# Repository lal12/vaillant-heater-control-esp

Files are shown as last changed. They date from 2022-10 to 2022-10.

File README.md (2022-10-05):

# Vaillant heater control

This project contains a little board (and software) to control a Vaillant heater.

It is currently Work in Progress and not everything works!!

## PCB

/kicad

The schematic shows a PCB which controls the Vaillant heater via 789 interface which is just an analog voltage to control the flow temperature (Vorlauftemperatur).

## Esphome

/esphome

A simple config to use the PCB with an ESP32.

## NodeJS

/nodejs

Small NodeJS application, it reads out the data from the heater.
It isn't really well made and more intended for temporary and debugging purposes.

It will log the data to the console and a json log.
It will display a graph on a little webpage.
It will publish the data to mqtt in a HomeAssistant compatible format.

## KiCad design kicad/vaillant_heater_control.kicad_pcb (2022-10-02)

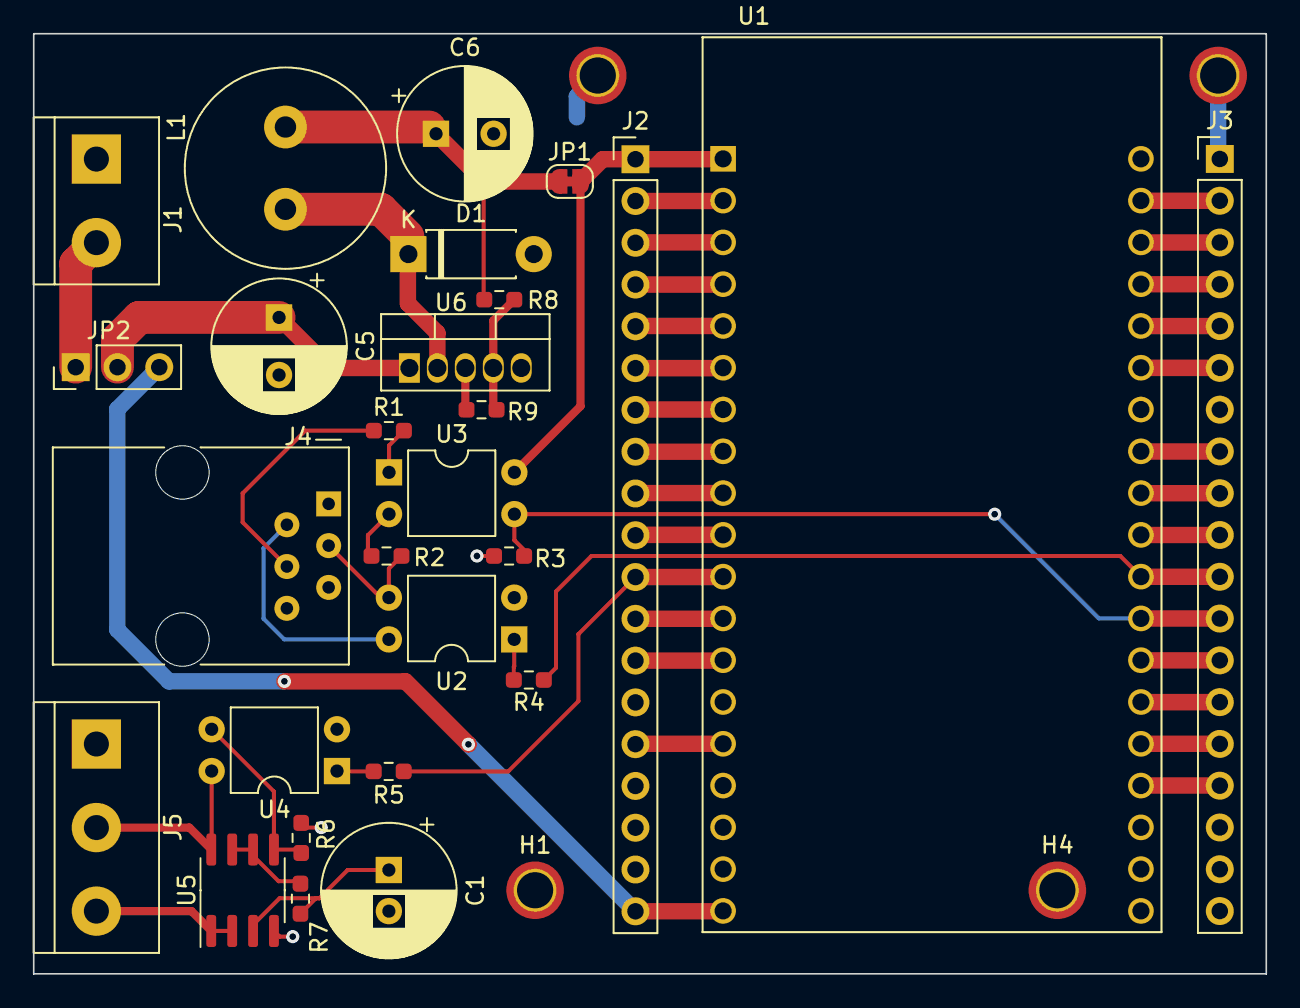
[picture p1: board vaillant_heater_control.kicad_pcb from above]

Board: 2 copper layers, 74.9 x 57.2 mm, 31 parts (0 on the bottom side), 48 nets.

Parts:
C1: 10u; CP_Radial_D8.0mm_P2.50mm
C5: 100u; CP_Radial_D8.0mm_P3.50mm
C6: 330u; CP_Radial_D8.0mm_P3.50mm
D1: 1n5819; D_DO-41_SOD81_P7.62mm_Horizontal
H1, H2, H3, H4: MountingHole_Pad; MountingHole_2.2mm_M2_ISO7380_Pad_TopBottom
J1: Screw_Terminal_01x02; TerminalBlock_bornier-2_P5.08mm
J2, J3: Conn_01x19; PinHeader_1x19_P2.54mm_Vertical
J4: 6P6C; RJ12_Amphenol_54601
J5: Screw_Terminal_01x03; TerminalBlock_bornier-3_P5.08mm
JP1: SolderJumper_2_Bridged; SolderJumper-2_P1.3mm_Bridged_RoundedPad1.0x1.5mm
JP2: Jumper_3_Bridged12; PinHeader_1x03_P2.54mm_Vertical
L1: 330u; L_Radial_D12.0mm_P5.00mm_Fastron_11P
R1, R5: 350; R_0603_1608Metric_Pad0.98x0.95mm_HandSolder
R2, R3, R6: 10k; R_0603_1608Metric_Pad0.98x0.95mm_HandSolder
R4: 180; R_0603_1608Metric_Pad0.98x0.95mm_HandSolder
R7: 500; R_0603_1608Metric_Pad0.98x0.95mm_HandSolder
R8: 3.4k; R_0603_1608Metric_Pad0.98x0.95mm_HandSolder
R9: 2k; R_0603_1608Metric_Pad0.98x0.95mm_HandSolder
U1: ESP32-DEVKITC-32D; MODULE_ESP32-DEVKITC-32D
U2, U3, U4: SFH617A-1; DIP-4_W7.62mm
U5: LM358; SOIC-8_3.9x4.9mm_P1.27mm
U6: LM2575BT-ADJ; TO-220-5_Vertical

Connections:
+3V3: J2.1, JP1.2 (B), U1.1 (3V3), U3.4
/789_analog/CTRL: J5.3, U5.1, U5.2 (-)
/789_analog/GND_789: C1.2, J5.1, R6.1, U5.4 (V-)
/789_analog/V_789: J5.2, U4.4, U5.8 (V+)
/power supply/PS_3V3: C6.1, JP1.1 (A), L1.2, R8.2
/power supply/Vin: C5.1, JP2.2 (C), U6.1 (VIN)
/serial/X6_5V: J4.2, U2.4
/serial/X6_GND: J4.5, R2.2, U3.2
/serial/X6_RXD: J4.3, R2.1, U2.3
/serial/X6_TXD: J4.4, R1.1
GND: C5.2, C6.2, D1.2 (A), H1.1, H2.1, H3.1, H4.1, J1.1, J2.14, J3.1, J3.7, R3.2, R9.1, U1.14 (GND1), U1.20 (GND3), U1.26 (GND2), U2.2, U4.2, U6.3 (GND), U6.5 (~ON/OFF)
IO27: J2.11, R5.1, U1.11 (IO27)
unnamed: C1.1, R7.2, U5.3 (+)
unnamed: J1.2, JP2.1 (A)
unnamed: J2.2, U1.2 (EN)
unnamed: J2.3, U1.3 (SENSOR_VP)
unnamed: J2.4, U1.4 (SENSOR_VN)
unnamed: J2.5, U1.5 (IO34)
unnamed: J2.6, U1.6 (IO35)
unnamed: J2.7, U1.7 (IO32)
unnamed: J2.8, U1.8 (IO33)
unnamed: J2.9, U1.9 (IO25)
unnamed: J2.10, U1.10 (IO26)
unnamed: J2.12, U1.12 (IO14)
unnamed: J2.13, U1.13 (IO12)
unnamed: J2.15, U1.15 (IO13)
unnamed: J3.2, U1.21 (IO23)
unnamed: J3.3, U1.22 (IO22)
unnamed: J3.4, U1.23 (TXD0)
unnamed: J3.5, U1.24 (RXD0)
unnamed: J3.6, U1.25 (IO21)
unnamed: J3.8, U1.27 (IO19)
unnamed: J3.9, U1.28 (IO18)
unnamed: J3.10, U1.29 (IO5)
unnamed: J3.13, U1.32 (IO4)
unnamed: J3.14, U1.33 (IO0)
unnamed: J3.15, U1.34 (IO2)
unnamed: J3.16, U1.35 (IO15)
unnamed: D1.1 (K), L1.1, U6.2 (OUT)
unnamed: R1.2, U3.1
unnamed: R4.1, U2.1
unnamed: R5.2, U4.1
unnamed: R6.2, U4.3, U5.5 (+)
unnamed: R7.1, U5.6 (-), U5.7
unnamed: R8.1, R9.2, U6.4 (FB)
RX: J3.12, R3.1, U1.31 (IO16), U3.3
TX: J3.11, R4.2, U1.30 (IO17)
V_USB: J2.19, JP2.3 (B), U1.19 (EXT_5V)

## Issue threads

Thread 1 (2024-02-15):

PCB production

mevlad24, 2024-02-15:
Hello,
please are you aware of anyone producing the PCB you are describing on your GH page?
Thank you
 Vladimir

lal12, 2024-02-15:
No. I only ordered a few for myself. However I had issues getting it to work anyway. The temperature controlling part works fine. But the serial part didn't work properly. I am not exactly sure what's the issue, probably the heater mcu doesn't provide enough current to drive the optoptocoupler at least while maintaining a clean signal.

I also had issues with other means, e.g. only some serial to USB converters worked and even the one which worked stopped after a while, the constant connection (and polling) might have broke the IOs in the heater. But I never really looked into that after more closely it stopped working.

LordTompa, 2024-02-15:
Hi, I built the Paltine a year ago. Only the part that is needed to control the temperature, but that's all I wanted.
Everything worked perfectly. I ordered the boards from Jlcpcb and still have 4 boards left.
If you are from Germany, it is no problem for me to send you 1-2 boards.
But as a note, the boards are unassembled and I'm pretty sure I don't have the required components anymore.
So you would have to get and solder them yourself

mevlad24, 2024-02-16:
Hi,
Thank you for your feedback and valuable experience shared.
@LordTompa I'm definitely interested in one board if you could sell it to me.  I will contact you on your private email to agree on further details.
BR, Vladimir

Closed 2024-04-11.
